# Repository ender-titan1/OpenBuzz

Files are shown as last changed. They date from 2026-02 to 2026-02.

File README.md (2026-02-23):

# OpenBuzz
OpenBuzz is a free and open source buzzer system for trivia games & tournaments, gameshows, or any competition where timing matters. It can be used with 2 teams of up to 4 players or with up to 8 independent players.

## Features
- Open source 
- Fully hand-solderable
- Modular and modifyable
- Designed to be fabricated as cheaply as possible
- Support for extensive customization, many game modes and a wide range of buzzer sounds
- Use of common RJ45 connector for easy and cheap connection between base and pods

## Why make this?
Professional buzzer systems tend to be very expensive and not very customizable, as well as being tricky to obtain due to overseas shipping. OpenBuzz aims to provide a cheaper and more flexible alternative, while maintaining fairness and accurate winner detection. It was originally designed for a local trivia team that needed a system to practice with, but since has been made open source. As a bonus it allows players to have their own custom buzzers, ranging from simple buttons to way over-the-top triggers.

# Usage
1. Download schematic and PCB files
2. Modify freely to fit your needs, components, etc...
3. Fabricate with any online service for as little as <$10
4. Assemble base and as many pods as you need
5. 3D-print enclosures if needed
6. Use in any game you need it for!

**Disclaimer: V1 is included in this repository for historical reference only. Versions V2 and above are the ones intended for use.**

PCB files and schematics are provided as KiCad files. 3D files for enclosures are provided as STEP files.

# License
The code and firmware included in the `src` folder is covered by the GNU General Public License v3.0, while the design files (schematics, PCB layout, 3D models) in the `hardware` folder are covered by the CERN Open Hardware Licence Version 2 - Strongly Reciprocal license. The full license texts can be found in their respective folders.

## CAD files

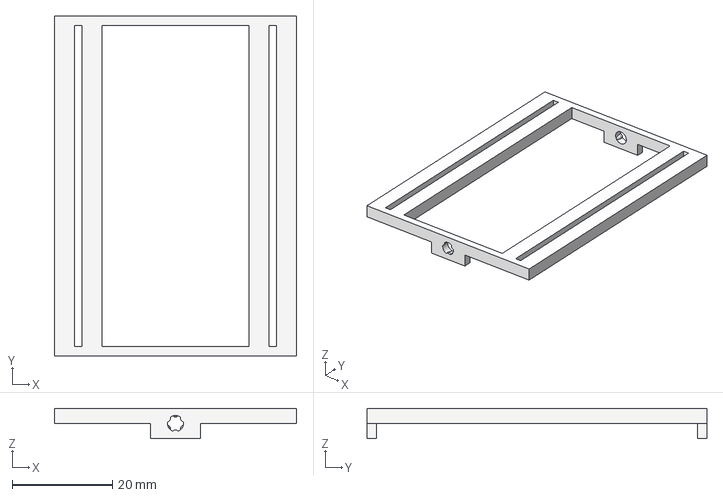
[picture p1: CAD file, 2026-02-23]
hardware/V1/Enclosures/Base/Minimal/LED Clip.step
48.4 x 67.9 x 6.00 mm

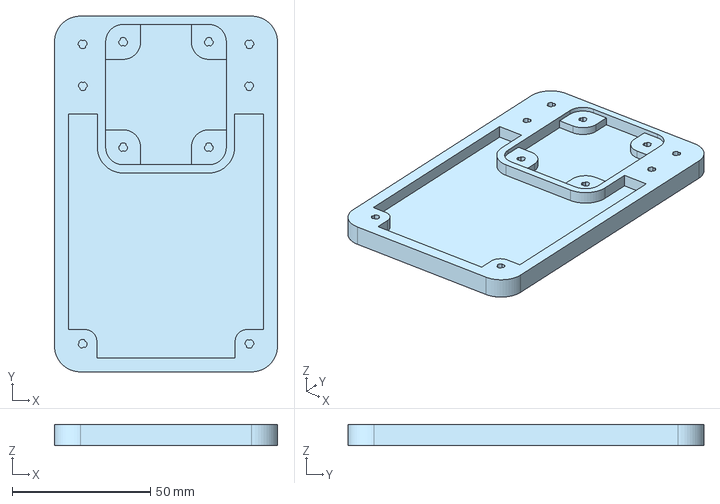
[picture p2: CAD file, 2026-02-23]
hardware/V1/Enclosures/Pod/Base.step
80.6 x 128.6 x 7.60 mm

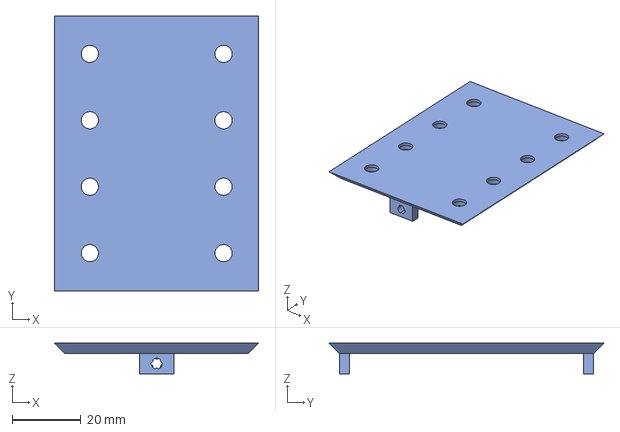
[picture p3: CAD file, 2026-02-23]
hardware/V1/Enclosures/Base/Minimal/LED Panel.step
59.3 x 79.9 x 9.00 mm

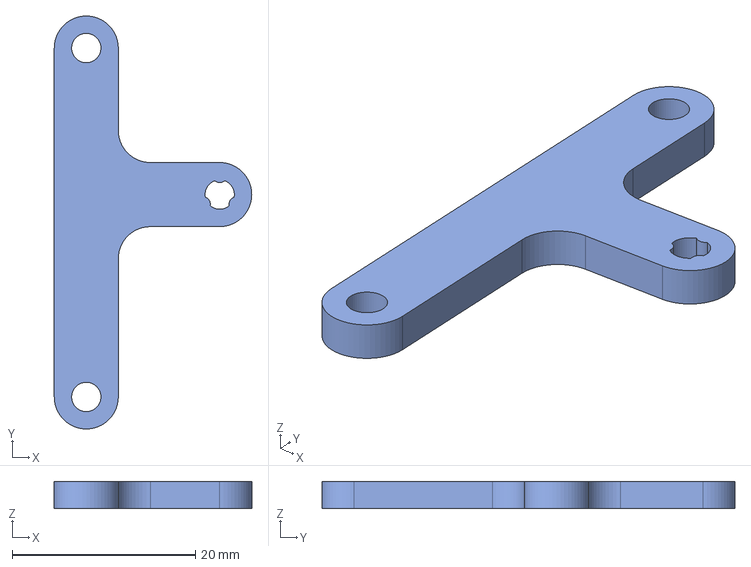
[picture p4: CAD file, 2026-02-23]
hardware/V1/Enclosures/Pod/Clip B.step
21.6 x 45.1 x 3.00 mm

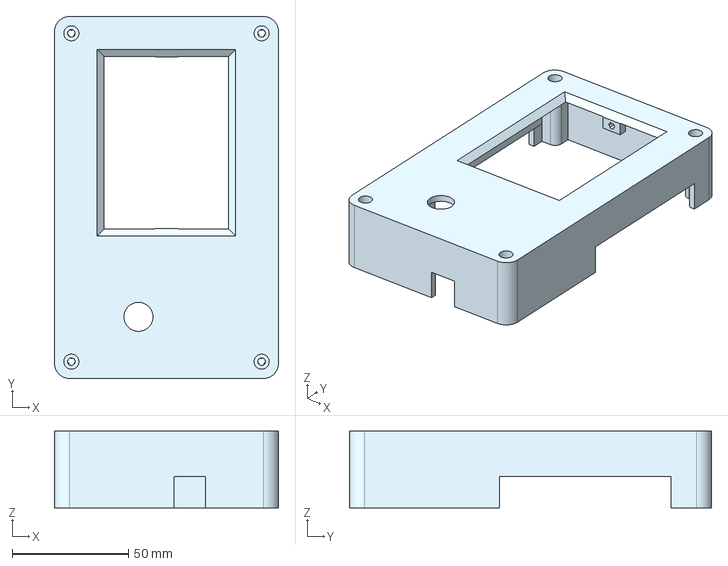
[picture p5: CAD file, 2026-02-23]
hardware/V1/Enclosures/Base/Minimal/Cover.step
96.4 x 155.9 x 33.0 mm

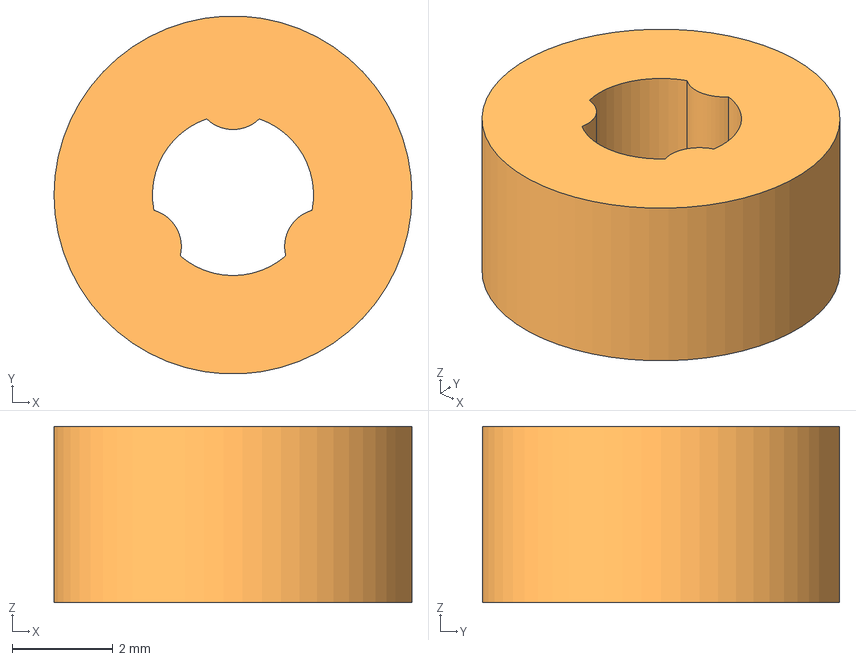
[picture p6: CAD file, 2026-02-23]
hardware/V1/Enclosures/Base/Minimal/Spacer.step
7.11 x 7.10 x 3.50 mm

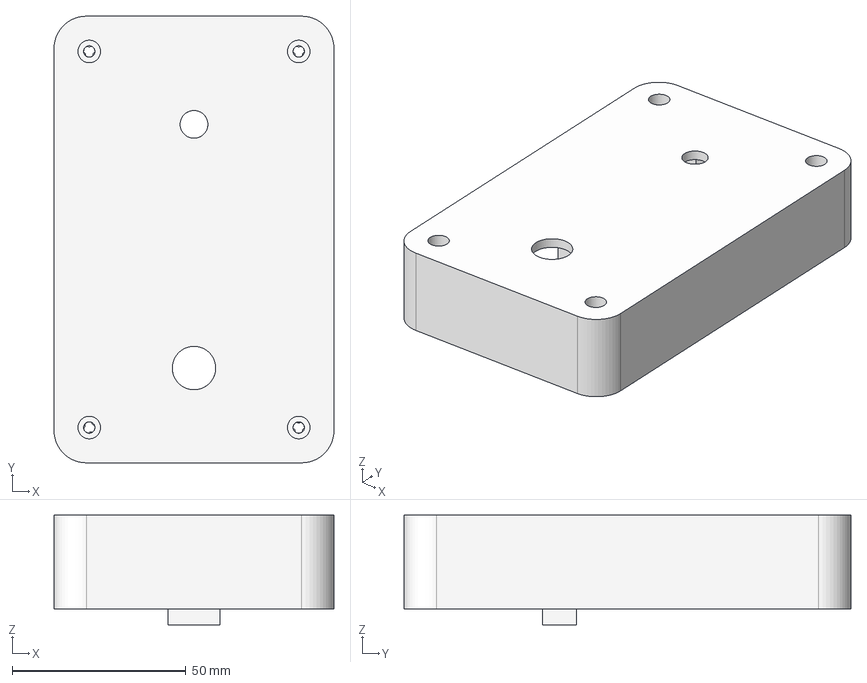
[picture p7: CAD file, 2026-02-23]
hardware/V1/Enclosures/Pod/Cover.step
80.6 x 128.6 x 31.6 mm

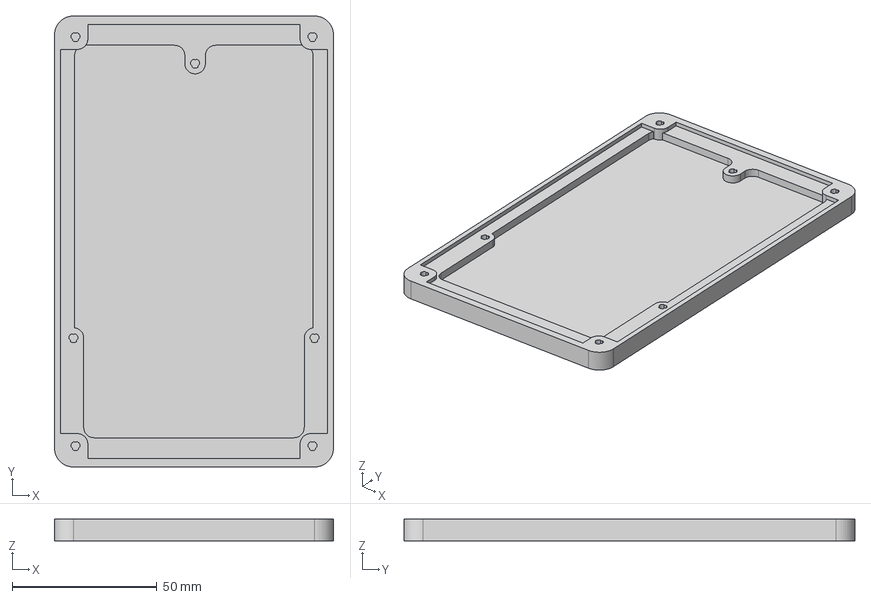
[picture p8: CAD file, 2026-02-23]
hardware/V1/Enclosures/Base/Minimal/Base.step
96.4 x 155.9 x 7.60 mm

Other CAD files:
hardware/V1/Enclosures/Pod/Clip A.step

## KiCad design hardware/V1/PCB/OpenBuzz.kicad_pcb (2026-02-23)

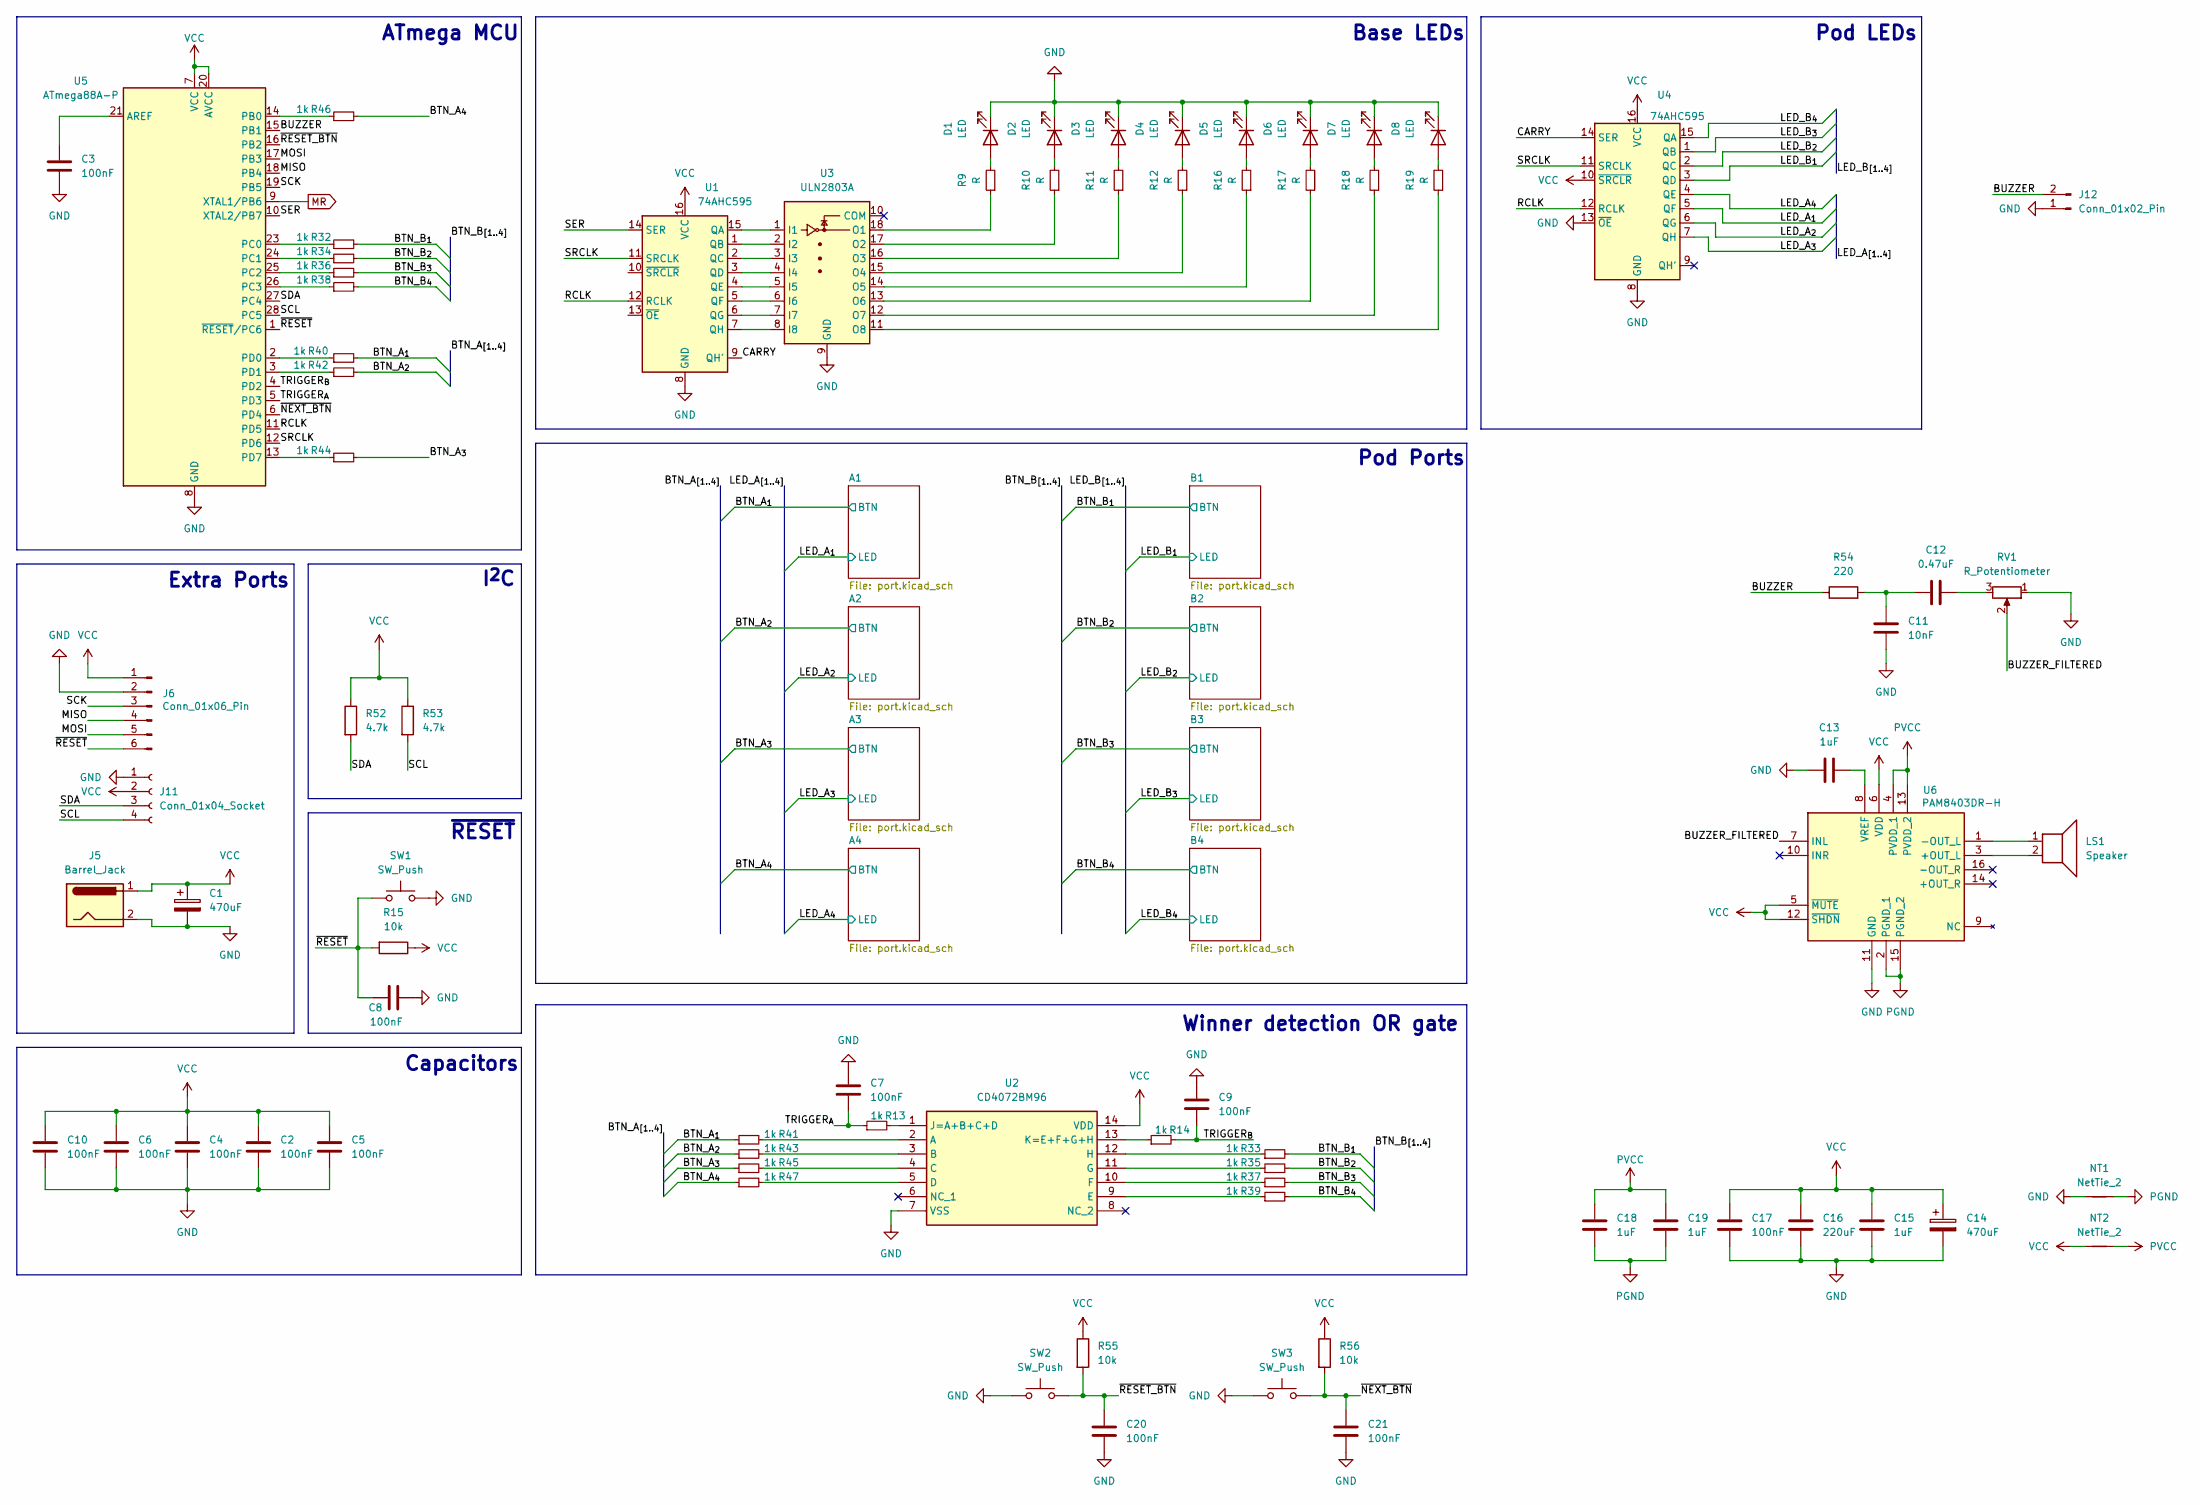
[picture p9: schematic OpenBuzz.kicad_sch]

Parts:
C1, C14: 470uF; CP_Radial_D8.0mm_P3.50mm
C2, C3, C4, C5, C6, C7, C8, C9, C10, C17, C20, C21: 100nF; C_0805_2012Metric_Pad1.18x1.45mm_HandSolder
C11: 10nF; C_0805_2012Metric_Pad1.18x1.45mm_HandSolder
C12: 0.47uF; C_0805_2012Metric_Pad1.18x1.45mm_HandSolder
C13, C15, C18, C19: 1uF; C_0805_2012Metric_Pad1.18x1.45mm_HandSolder
C16: 220uF; C_0805_2012Metric_Pad1.18x1.45mm_HandSolder
D1, D2, D3, D4, D5, D6, D7, D8: LED; LED_D5.0mm
J5: Barrel_Jack; BarrelJack_Horizontal
J6: Conn_01x06_Pin; PinHeader_1x06_P2.54mm_Vertical
J11: Conn_01x04_Socket; NS-Tech_Grove_1x04_P2mm_Vertical
J12: Conn_01x02_Pin; PinHeader_1x02_P2.54mm_Vertical
LS1: Speaker; PinHeader_1x02_P2.54mm_Vertical
NT1, NT2: NetTie_2; NetTie-2_SMD_Pad2.0mm
R9, R10, R11, R12, R16, R17, R18, R19: R; R_0805_2012Metric_Pad1.20x1.40mm_HandSolder
R13, R14, R32, R33, R34, R35, R36, R37, R38, R39, R40, R41, R42, R43, R44, R45, R46, R47: 1k; R_0805_2012Metric_Pad1.20x1.40mm_HandSolder
R15, R55, R56: 10k; R_0805_2012Metric_Pad1.20x1.40mm_HandSolder
R52, R53: 4.7k; R_0805_2012Metric_Pad1.20x1.40mm_HandSolder
R54: 220; R_0805_2012Metric_Pad1.20x1.40mm_HandSolder
RV1: R_Potentiometer; PinHeader_1x03_P2.54mm_Vertical
SW1: SW_Push; SW_Push_1P1T_NO_CK_KSC6xxJ
SW2, SW3: SW_Push; PinHeader_1x02_P2.54mm_Vertical
U1, U4: 74AHC595; DIP-16_W7.62mm_Socket_LongPads
U2: CD4072BM96; SOIC-14_3.9x8.7mm_P1.27mm; Mouser Part Number 595-CD4072BE
U3: ULN2803A; DIP-18_W7.62mm_Socket_LongPads
U5: ATmega88A-P; DIP-28_W7.62mm_Socket_LongPads
U6: PAM8403DR-H; SOIC-16_3.9x9.9mm_P1.27mm; Manufacturer_Part_Number PAM8403DR-H

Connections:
/BTN_A_{1}: R40.2, R41.1; also elsewhere on the board
/BTN_A_{2}: R42.2, R43.1; also elsewhere on the board
/BTN_A_{3}: R44.2, R45.1; also elsewhere on the board
/BTN_A_{4}: R46.2, R47.1; also elsewhere on the board
/BTN_B_{1}: R32.2, R33.2; also elsewhere on the board
/BTN_B_{2}: R34.2, R35.2; also elsewhere on the board
/BTN_B_{3}: R36.2, R37.2; also elsewhere on the board
/BTN_B_{4}: R38.2, R39.2; also elsewhere on the board
/BUZZER: J12.2, R54.1, U5.15 (PB1)
/BUZZER_FILTERED: RV1.2, U6.7 (INL)
/CARRY: U1.9 (QH'), U4.14 (SER)
/LED_A_{1}: U4.5 (QF); also elsewhere on the board
/LED_A_{2}: U4.6 (QG); also elsewhere on the board
/LED_A_{3}: U4.7 (QH); also elsewhere on the board
/LED_A_{4}: U4.4 (QE); also elsewhere on the board
/LED_B_{1}: U4.3 (QD); also elsewhere on the board
/LED_B_{2}: U4.2 (QC); also elsewhere on the board
/LED_B_{3}: U4.1 (QB); also elsewhere on the board
/LED_B_{4}: U4.15 (QA); also elsewhere on the board
/MISO: J6.4, U5.18 (PB4)
/MOSI: J6.5, U5.17 (PB3)
/RCLK: U1.12 (RCLK), U4.12 (RCLK), U5.11 (PD5)
/SCK: J6.3, U5.19 (PB5)
/SCL: J11.4, R53.2, U5.28 (PC5)
/SDA: J11.3, R52.2, U5.27 (PC4)
/SER: U1.14 (SER), U5.10 (XTAL2/PB7)
/SRCLK: U1.11 (SRCLK), U4.11 (SRCLK), U5.12 (PD6)
/TRIGGER_{A}: C7.2, R13.1, U5.5 (PD3)
/TRIGGER_{B}: C9.2, R14.2, U5.4 (PD2)
/~NEXT_BTN: C21.1, R56.2, SW3.2, U5.6 (PD4)
/~RESET_BTN: C20.1, R55.2, SW2.2, U5.16 (PB2)
/~RESET: C8.2, J6.6, R15.2, SW1.1, U5.1 (~RESET/PC6)
GND: C1.2, C2.2, C3.2, C4.2, C5.2, C6.2, C7.1, C8.1, C9.1, C10.2, C11.2, C13.1, C14.2, C15.2, C16.2, C17.2, C20.2, C21.2, D1.1 (K), D2.1 (K), D3.1 (K), D4.1 (K), D5.1 (K), D6.1 (K), D7.1 (K), D8.1 (K), J5.2, J6.2, J11.1, J12.1, NT1.1, RV1.1, SW1.2, SW2.1, SW3.1, U1.8 (GND), U2.7 (VSS), U3.9 (GND), U4.8 (GND), U4.13 (~OE), U5.8 (GND), U5.22 (GND), U6.11 (GND); also elsewhere on the board
MR: U5.9 (XTAL1/PB6); also elsewhere on the board
unnamed: C11.1, C12.1, R54.2
unnamed: C12.2, RV1.3
unnamed: D1.2 (A), R9.2
unnamed: D2.2 (A), R10.2
unnamed: D3.2 (A), R11.2
unnamed: D4.2 (A), R12.2
unnamed: D5.2 (A), R16.2
unnamed: D6.2 (A), R17.2
unnamed: D7.2 (A), R18.2
unnamed: D8.2 (A), R19.2
unnamed: U1.15 (QA), U3.1 (I1)
unnamed: U1.1 (QB), U3.2 (I2)
unnamed: U1.2 (QC), U3.3 (I3)
unnamed: U1.3 (QD), U3.4 (I4)
unnamed: U1.4 (QE), U3.5 (I5)
unnamed: U1.5 (QF), U3.6 (I6)
unnamed: U1.6 (QG), U3.7 (I7)
unnamed: U1.7 (QH), U3.8 (I8)
unnamed: R41.2, U2.2 (A)
unnamed: R43.2, U2.3 (B)
unnamed: R45.2, U2.4 (C)
unnamed: R47.2, U2.5 (D)
unnamed: R39.1, U2.9 (E)
unnamed: R37.1, U2.10 (F)
unnamed: R35.1, U2.11 (G)
unnamed: R33.1, U2.12 (H)
unnamed: R13.2, U2.1 (J=A+B+C+D)
unnamed: R14.1, U2.13 (K=E+F+G+H)
unnamed: R9.1, U3.18 (O1)
unnamed: R10.1, U3.17 (O2)
unnamed: R11.1, U3.16 (O3)
unnamed: R12.1, U3.15 (O4)
unnamed: R16.1, U3.14 (O5)
unnamed: R17.1, U3.13 (O6)
unnamed: R18.1, U3.12 (O7)
unnamed: R19.1, U3.11 (O8)
unnamed: C3.1, U5.21 (AREF)
unnamed: R46.1, U5.14 (PB0)
unnamed: R32.1, U5.23 (PC0)
unnamed: R34.1, U5.24 (PC1)
unnamed: R36.1, U5.25 (PC2)
unnamed: R38.1, U5.26 (PC3)
unnamed: R40.1, U5.2 (PD0)
unnamed: R42.1, U5.3 (PD1)
unnamed: R44.1, U5.13 (PD7)
unnamed: LS1.2, U6.3 (+OUT_L)
unnamed: LS1.1, U6.1 (-OUT_L)
unnamed: C13.2, U6.8 (VREF)
PGND: C18.2, C19.2, NT1.2, U6.2 (PGND_1), U6.15 (PGND_2)
PVCC: C18.1, C19.1, NT2.2, U6.4 (PVDD_1), U6.13 (PVDD_2)
VCC: C1.1, C2.1, C4.1, C5.1, C6.1, C10.1, C14.1, C15.1, C16.1, C17.1, J5.1, J6.1, J11.2, NT2.1, R15.1, R52.1, R53.1, R55.1, R56.1, U1.16 (VCC), U2.14 (VDD), U4.10 (~SRCLR), U4.16 (VCC), U5.7 (VCC), U5.20 (AVCC), U6.5 (~MUTE), U6.6 (VDD), U6.12 (~SHDN); also elsewhere on the board

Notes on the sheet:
Base LEDs
~{RESET}
Pod LEDs
ATmega MCU
Pod Ports
I^{2}C
Extra Ports
Capacitors
Winner detection OR gate

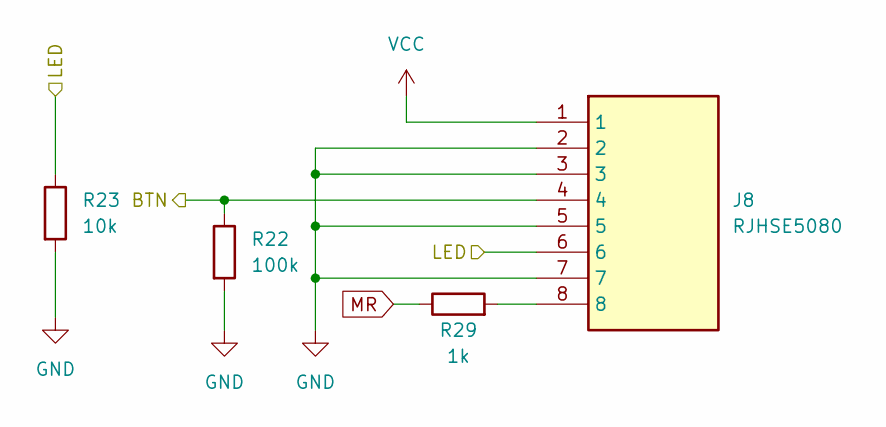
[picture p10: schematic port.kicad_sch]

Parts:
J8: RJHSE5080; Manufacturer_Part_Number RJHSE5080
R22: 100k; R_0805_2012Metric_Pad1.20x1.40mm_HandSolder
R23: 10k; R_0805_2012Metric_Pad1.20x1.40mm_HandSolder
R29: 1k; R_0805_2012Metric_Pad1.20x1.40mm_HandSolder

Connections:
/BTN_B_{2}: J8.4, R22.1; also elsewhere on the board
/LED_B_{2}: J8.6, R23.1; also elsewhere on the board
GND: J8.2, J8.3, J8.5, J8.7, R22.2, R23.2; also elsewhere on the board
MR: R29.1; also elsewhere on the board
unnamed: J8.8, R29.2
VCC: J8.1; also elsewhere on the board

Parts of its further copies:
J1, J2, J3, J4, J7, J9, J10: RJHSE5080; Manufacturer_Part_Number RJHSE5080
R1, R3, R5, R7, R21, R25, R27: 10k; R_0805_2012Metric_Pad1.20x1.40mm_HandSolder
R2, R4, R6, R8, R20, R24, R26: 100k; R_0805_2012Metric_Pad1.20x1.40mm_HandSolder
R28, R30, R31, R48, R49, R50, R51: 1k; R_0805_2012Metric_Pad1.20x1.40mm_HandSolder

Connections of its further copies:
/BTN_A_{1}: J1.4, R2.1; also elsewhere on the board
/BTN_A_{2}: J2.4, R4.1; also elsewhere on the board
/BTN_A_{3}: J3.4, R6.1; also elsewhere on the board
/BTN_A_{4}: J4.4, R8.1; also elsewhere on the board
/BTN_B_{1}: J7.4, R20.1; also elsewhere on the board
/BTN_B_{3}: J9.4, R24.1; also elsewhere on the board
/BTN_B_{4}: J10.4, R26.1; also elsewhere on the board
/LED_A_{1}: J1.6, R1.1; also elsewhere on the board
/LED_A_{2}: J2.6, R3.1; also elsewhere on the board
/LED_A_{3}: J3.6, R5.1; also elsewhere on the board
/LED_A_{4}: J4.6, R7.1; also elsewhere on the board
/LED_B_{1}: J7.6, R21.1; also elsewhere on the board
/LED_B_{3}: J9.6, R25.1; also elsewhere on the board
/LED_B_{4}: J10.6, R27.1; also elsewhere on the board
GND: J1.2, J1.3, J1.5, J1.7, J2.2, J2.3, J2.5, J2.7, J3.2, J3.3, J3.5, J3.7, J4.2, J4.3, J4.5, J4.7, J7.2, J7.3, J7.5, J7.7, J9.2, J9.3, J9.5, J9.7, J10.2, J10.3, J10.5, J10.7, R1.2, R2.2, R3.2, R4.2, R5.2, R6.2, R7.2, R8.2, R20.2, R21.2, R24.2, R25.2, R26.2, R27.2; also elsewhere on the board
MR: R28.1, R30.1, R31.1, R48.1, R49.1, R50.1, R51.1; also elsewhere on the board
unnamed: J1.8, R48.2
unnamed: J2.8, R49.2
unnamed: J3.8, R50.2
unnamed: J4.8, R51.2
unnamed: J7.8, R28.2
unnamed: J9.8, R30.2
unnamed: J10.8, R31.2
VCC: J1.1, J2.1, J3.1, J4.1, J7.1, J9.1, J10.1; also elsewhere on the board

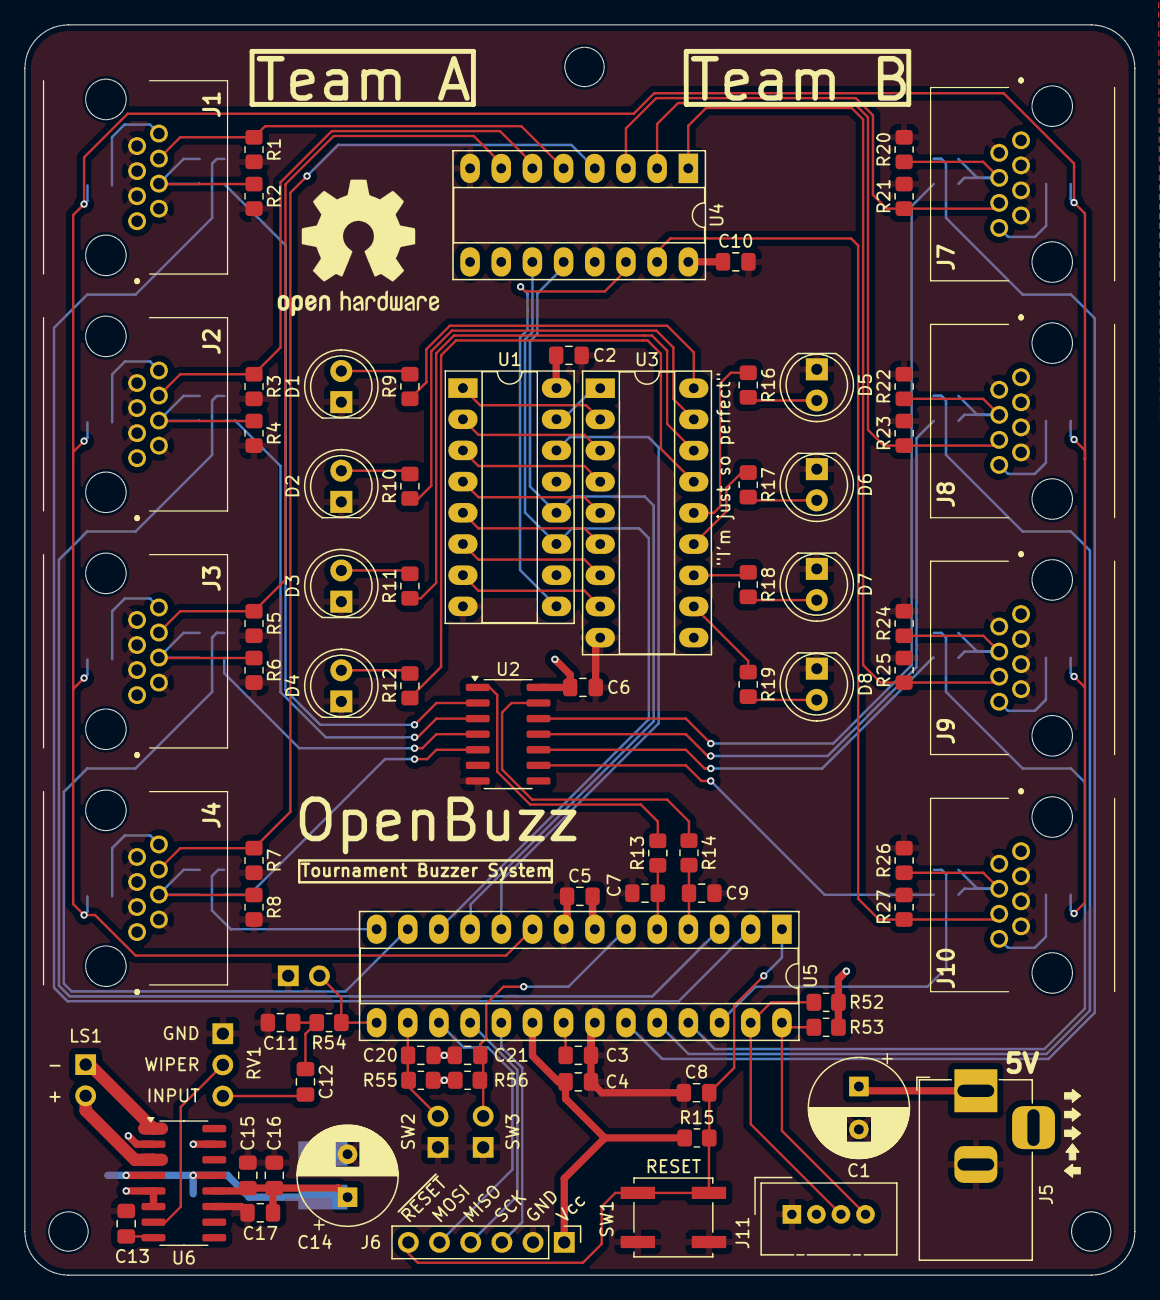
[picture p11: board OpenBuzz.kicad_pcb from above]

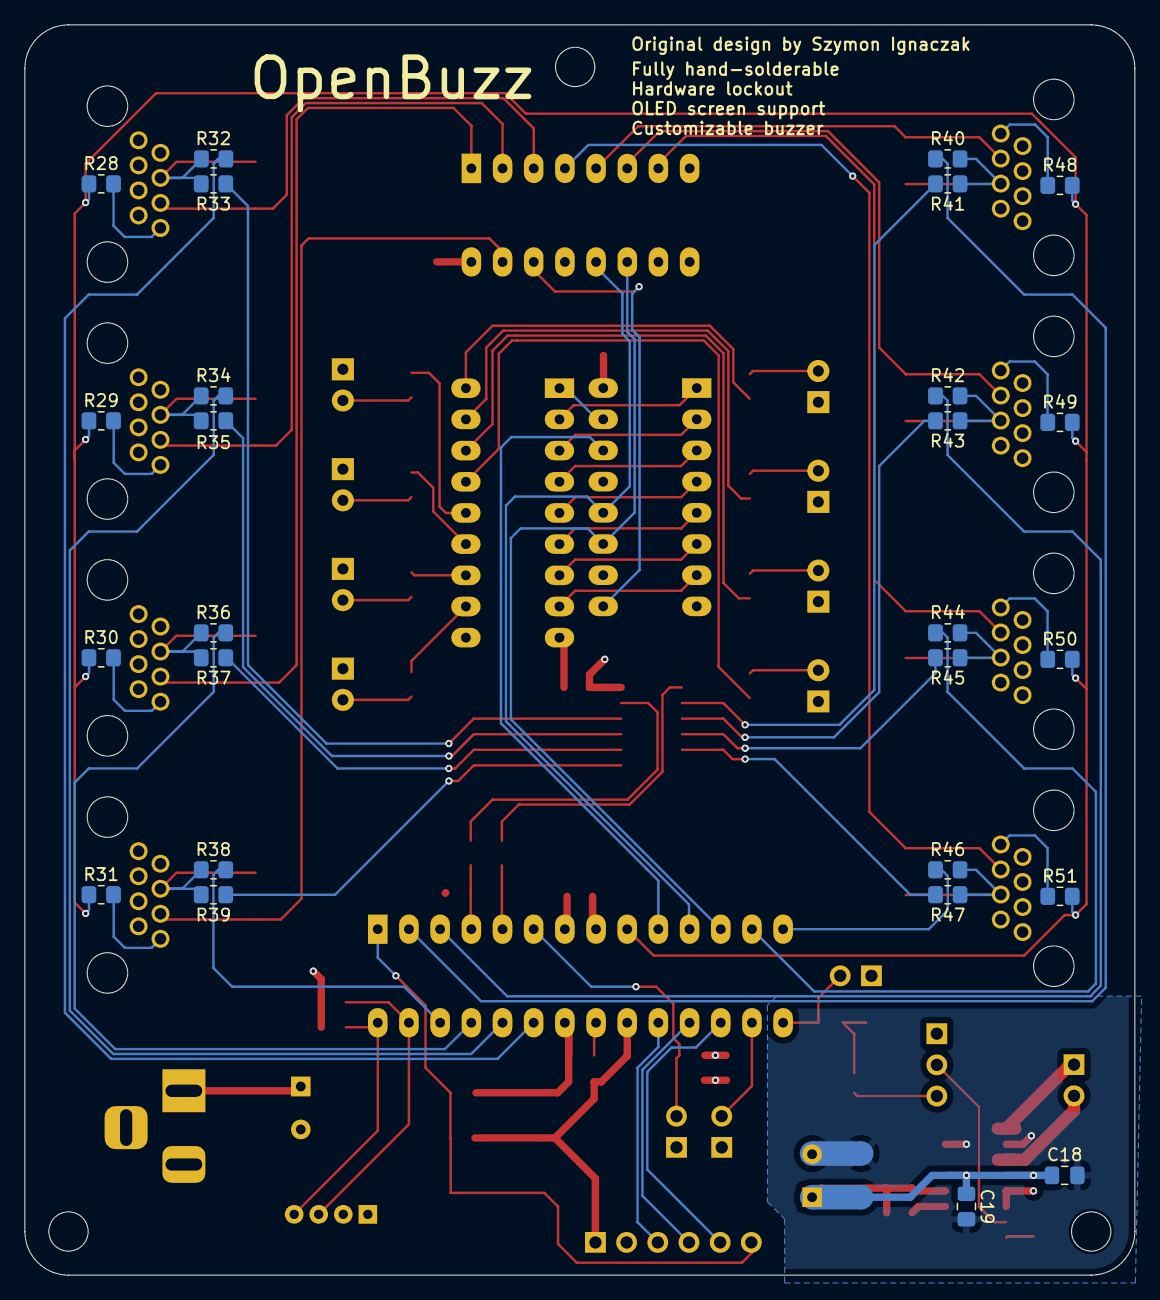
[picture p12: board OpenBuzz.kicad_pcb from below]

Board: 4 copper layers, 90.4 x 101.9 mm, 110 parts (28 on the bottom side), 93 nets.

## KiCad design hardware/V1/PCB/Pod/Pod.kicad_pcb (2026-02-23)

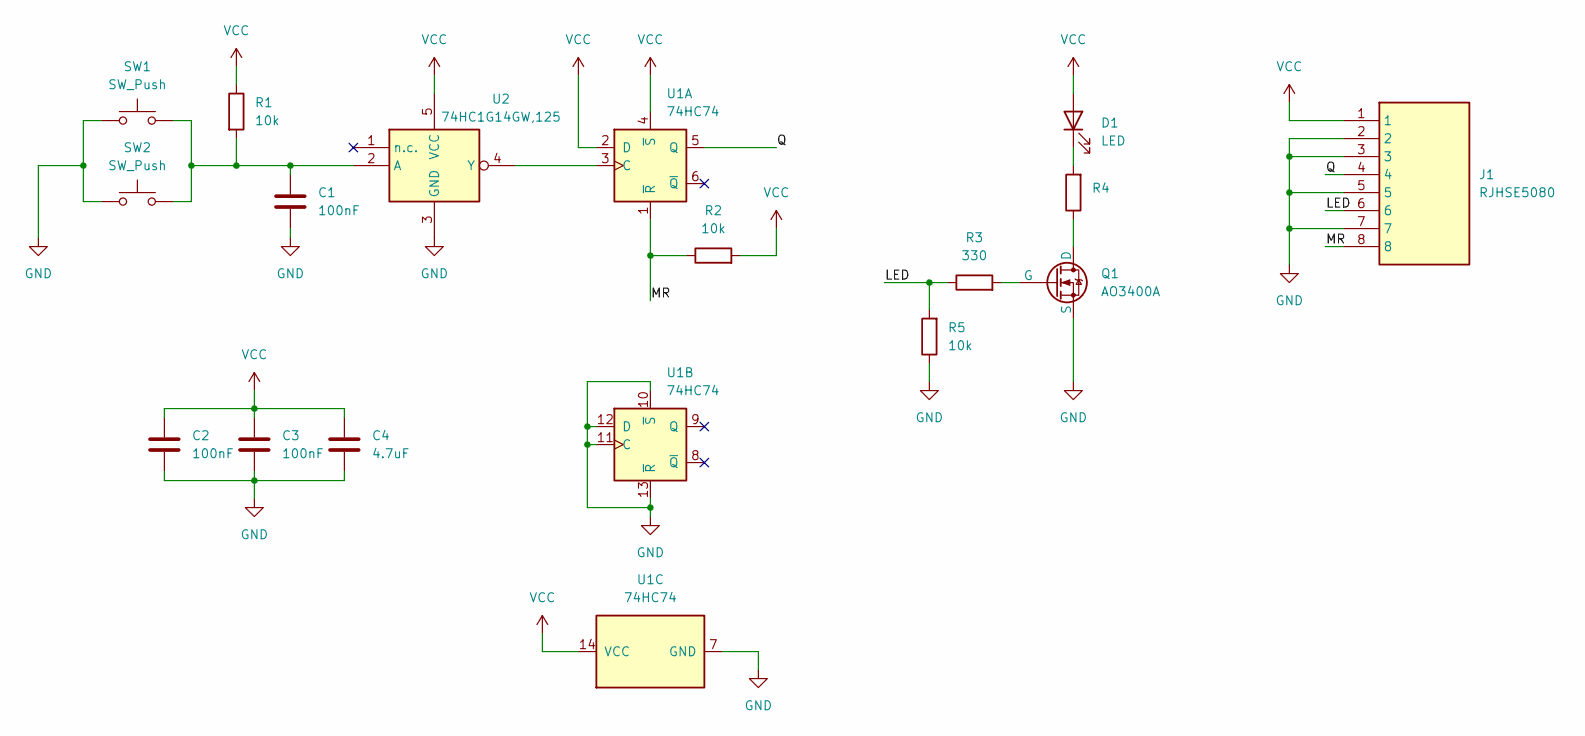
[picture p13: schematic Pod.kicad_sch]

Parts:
C1, C2, C3: 100nF; C_0805_2012Metric_Pad1.18x1.45mm_HandSolder
C4: 4.7uF; C_0805_2012Metric_Pad1.18x1.45mm_HandSolder
D1: LED; LED_D5.0mm
J1: RJHSE5080; Manufacturer_Part_Number RJHSE5080
Q1: AO3400A; SOT-23_Handsoldering
R1, R2, R5: 10k; R_0805_2012Metric_Pad1.20x1.40mm_HandSolder
R3: 330; R_0805_2012Metric_Pad1.20x1.40mm_HandSolder
R4: R_0805_2012Metric_Pad1.20x1.40mm_HandSolder
SW1: SW_Push; PinHeader_1x02_P2.54mm_Vertical
SW2: SW_Push; SW_Push_1P1T_NO_CK_KSC6xxJ
U1: 74HC74; SOIC-14_3.9x8.7mm_P1.27mm
U2: 74HC1G14GW,125; SOT-23-5_HandSoldering; Manufacturer_Part_Number 74HC1G14GW,125

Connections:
/LED: J1.6, R3.1, R5.2
/MR: J1.8, R2.1, U1.1 (~R)
/Q: J1.4, U1.5 (Q)
GND: C1.1, C2.1, C3.1, C4.2, J1.2, J1.3, J1.5, J1.7, Q1.3 (S), R5.1, SW1.1, SW2.1, U1.7 (GND), U1.10 (~S), U1.11 (C), U1.12 (D), U1.13 (~R), U2.3 (GND)
unnamed: D1.1 (K), R4.2
unnamed: Q1.1 (D), R4.1
unnamed: Q1.2 (G), R3.2
unnamed: U1.3 (C), U2.4 (Y)
unnamed: C1.2, R1.2, SW1.2, SW2.2, U2.2 (A)
VCC: C2.2, C3.2, C4.1, D1.2 (A), J1.1, R1.1, R2.2, U1.2 (D), U1.4 (~S), U1.14 (VCC), U2.5 (VCC)

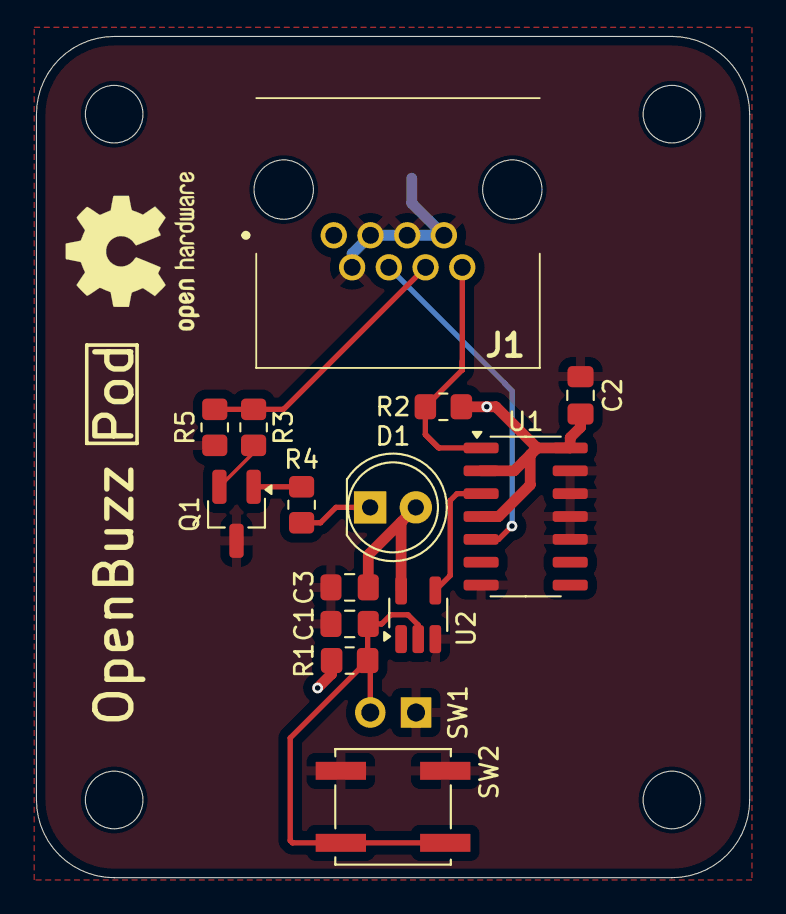
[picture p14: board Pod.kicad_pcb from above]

Board: 2 copper layers, 39.6 x 46.7 mm, 16 parts (1 on the bottom side), 10 nets.

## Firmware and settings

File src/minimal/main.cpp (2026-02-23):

#include <stdint.h>
#include "Arduino.h"
#include "avr/io.h"

// Minimal Version of the controller script for OpenBuzz V1:
//    - Winner detection
//    - Tone generation (with piezo buzzer on pin 9)
//    - Master reset

// MCU pins
#define SER 21
#define SRCLK 6
#define RCLK 5
#define MR 20       // Active LOW 
#define BUZZER 9
#define RST_BTN 10  // Active LOW

// Teams
#define TEAM_A 0
#define TEAM_B 1
#define NO_TEAM 0xFF

// Tones
#define TEAM_A_TONE 3500
#define TEAM_B_TONE 3300
#define TONE_DURATION_MS 300

// Player input pins
#define A1 PB0
#define A2 PD1
#define A3 PD7
#define A4 PD0

#define B1 PC0
#define B2 PC1
#define B3 PC2
#define B4 PC3

uint8_t pod_led_lookup_team_a[] = {
  0b00000000,
  0b00100000,
  0b01000000,
  0b10000000,
  0b00010000,
};

// Status variables
volatile uint8_t team_buzzed = NO_TEAM;
volatile bool buzzed = false;
bool handled = false;

// Input buffer
volatile uint8_t snapshotB;
volatile uint8_t snapshotC;
volatile uint8_t snapshotD;

void initMCU() {
  // Set all pins as inputs unless overriden
  DDRB = 0x00;
  DDRC = 0x00;
  DDRD = 0x00;

  pinMode(SER, OUTPUT);
  pinMode(SRCLK, OUTPUT);
  pinMode(RCLK, OUTPUT);
  pinMode(MR, OUTPUT);
  pinMode(BUZZER, OUTPUT);

  digitalWrite(MR, true);
}

void initInterrputs() {
  pinMode(2, INPUT); // INT0 / TEAM B
  pinMode(3, INPUT); // INT1 / TEAM A

  EIMSK |= _BV(INT0) | _BV(INT1); // Enable INT0 and INT1
  EICRA = 0b00001111; // Trigger both on rising edge (ISC = 0b11)

  sei();
}

void shift(uint16_t output) {
  digitalWrite(RCLK, false);
  shiftOut(SER, SRCLK, MSBFIRST, output >> 8);
  shiftOut(SER, SRCLK, MSBFIRST, output & 0xFF);
  digitalWrite(RCLK, true);
}

void selectLED(uint8_t team, uint8_t player) {
  uint8_t base_LEDs = (1 << (player - 1 + team * 4));
  uint8_t pod_LEDs = 0x00;
  
  if (team == TEAM_B)
    pod_LEDs = (1 << (4 - player + !team * 4));
  else
    pod_LEDs = pod_led_lookup_team_a[player];

  uint16_t output = (pod_LEDs << 8) + base_LEDs;

  shift(output);
}

void clearLED() {
  shift(0x0000);
}

void resetBuzzers() {
  digitalWrite(MR, false);
  delay(1);
  digitalWrite(MR, true);

  clearLED();
  buzzed = false;
  handled = false;
  team_buzzed = NO_TEAM;
}

void handleBuzz() {
  uint8_t player = 0;

  if (team_buzzed == TEAM_A) {
    if (snapshotB & _BV(A1))
      player = 1;

    if (snapshotD & _BV(A2))
      player = 2;

    if (snapshotD & _BV(A3))
      player = 3;

    if (snapshotD & _BV(A4))
      player = 4;
    
    tone(BUZZER, TEAM_A_TONE, TONE_DURATION_MS);
  }

  if (team_buzzed == TEAM_B) {
    if (snapshotC & _BV(B1))
      player = 1;

    if (snapshotC & _BV(B2))
      player = 2;

    if (snapshotC & _BV(B3))
      player = 3;

    if (snapshotC & _BV(B4))
      player = 4;
  
    tone(BUZZER, TEAM_B_TONE, TONE_DURATION_MS);
  }

  selectLED(team_buzzed, player);
}

int main() {
  init();
  initMCU();
  initInterrputs();
  clearLED();

  while (true) {
    if (buzzed && !handled) {
      handleBuzz();
      handled = true;
    }

    if (!digitalRead(RST_BTN)) {
      resetBuzzers();
    }
  }
}

// Team B buzzed
ISR(INT0_vect) {
  if (!buzzed) {
    snapshotB = PINB;
    snapshotC = PINC;
    snapshotD = PIND;

    buzzed = true;
    team_buzzed = TEAM_B;
  }
}

// Team A buzzed
ISR(INT1_vect) {
  if (!buzzed) {
    snapshotB = PINB;
    snapshotC = PINC;
    snapshotD = PIND;

    buzzed = true;
    team_buzzed = TEAM_A;
  }
}
